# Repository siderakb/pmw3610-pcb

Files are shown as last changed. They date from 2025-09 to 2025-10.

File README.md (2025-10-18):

# PMW3610 PCB




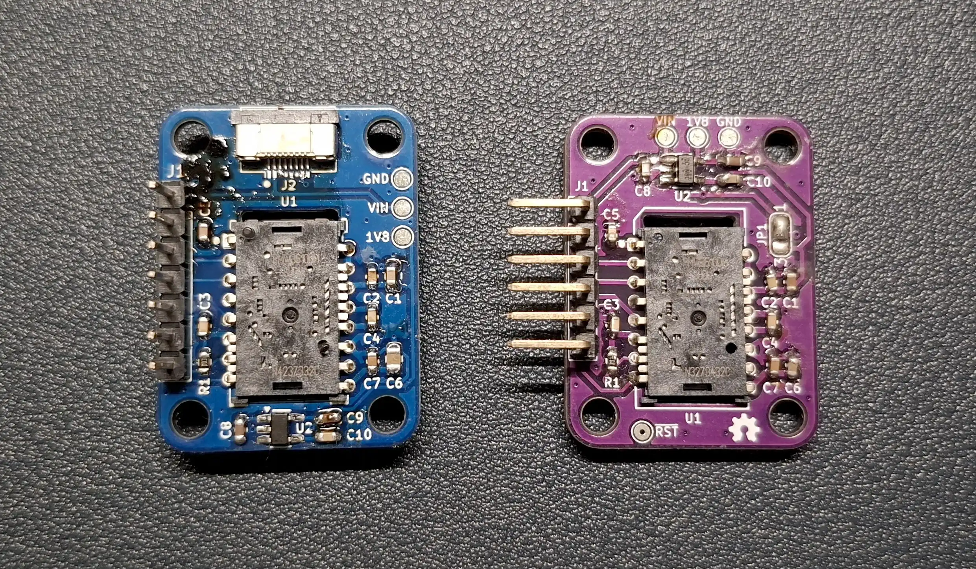
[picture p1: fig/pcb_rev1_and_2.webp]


Breakout board for the [PixArt PMW3610DM-SUDU](https://www.pixart.com/products-detail/21/PMW3610DM-SUDU), a low-power laser mouse sensor. An alternative to the [PMW3360 PCB](https://github.com/siderakb/pmw3360-pcb) for low-power applications. Can be used to make a mouse or trackball.

✨ Features:

- Compatible with [ZMK](https://zmk.dev/) projects. [Demo video](https://youtu.be/nyLZ6U8h7f0?t=17)
- Operates at either 1.8V or 3.3V voltage levels.
- Supports both 2.54mm pin headers and 0.5mm-pitch FFC/FPC connectors.
- The optical center of the sensor is located in the center of the PCB.

## PCB

Online preview available [here](https://kicanvas.org/?github=https%3A%2F%2Fgithub.com%2Fsiderakb%2Fpmw3610-pcb), powered by [KiCanvas](https://github.com/theacodes/kicanvas).

<a href="https://raw.githubusercontent.com/siderakb/pmw3610-pcb/refs/heads/main/fig/schematic.webp" target="_blank">
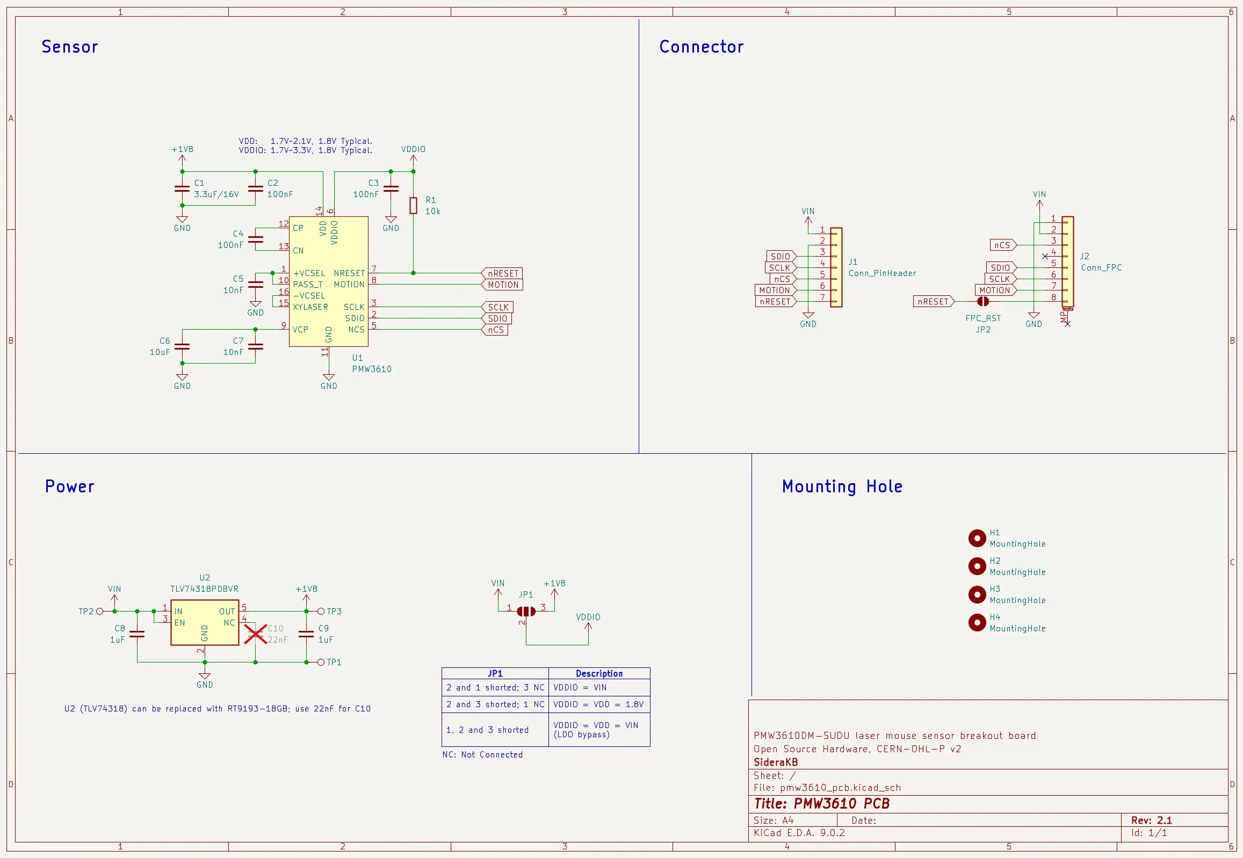
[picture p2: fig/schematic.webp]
schematic
  
</a>
<a href="https://raw.githubusercontent.com/siderakb/pmw3610-pcb/refs/heads/main/fig/layout.webp" target="_blank">
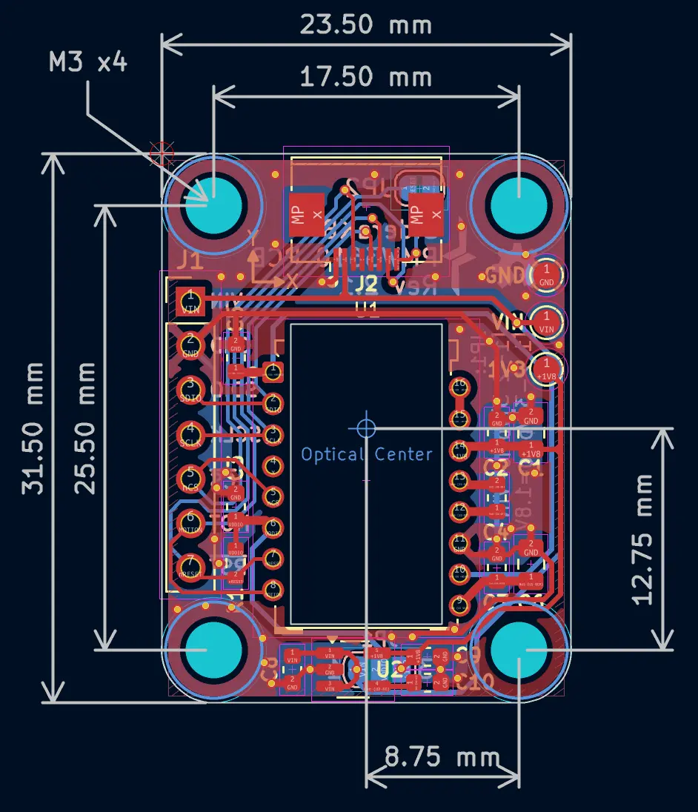
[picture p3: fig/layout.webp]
layout
  
</a>

## Docs

📖 For more detailed information, please refer to the [docs](https://siderakb.ziteh.dev/mouse-sensors/pmw3610/rev2/) ([alternative link](https://github.com/siderakb/siderakb-website/blob/starlight/main/src/content/docs/mouse-sensors/pmw3610/rev2.md)).

[Changelog](./CHANGELOG.md)

## License

- **Hardware**: Available under the [CERN-OHL-P v2](/LICENSE) permissive license.
- **Firmware**: Licensed under [Apache 2.0](https://spdx.org/licenses/Apache-2.0.html) as identified by the SPDX in each file.

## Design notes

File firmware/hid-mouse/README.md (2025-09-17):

# HID Mouse

This is a NCS (ZephyrRTOS) sample using the PMW3610 motion sensor with the nRF52840-DK. Refer to [pixart,pmw3610 (on spi bus) — Zephyr Project Documentation](https://docs.zephyrproject.org/latest/build/dts/api/bindings/input/pixart%2Cpmw3610.html).

Setup NCS: [nRF Connect SDK Fundamentals - Nordic Developer Academy](https://academy.nordicsemi.com/courses/nrf-connect-sdk-fundamentals/)

Pin mapping:

| PMW3610 PCB | nRF52840 |
| :---: | :---: |
| SDIO | `P0.31`  |
| SCLK | `P0.30`  |
| CS | `P0.29`  |
| MOTION | `P0.28`  |
| RESET | NC |

RTT logging backend. Example log:

```log
*** Booting nRF Connect SDK v3.1.0-6c6e5b32496e ***
*** Using Zephyr OS v4.1.99-1612683d4010 ***
[00:00:00.419,250] <inf> main: Starting PMW3610 example
[00:00:00.419,433] <inf> main: USB HID Initialized
[00:00:07.137,878] <inf> main: Motion X: 2
[00:00:07.137,908] <inf> main: Motion Y: -4
[00:00:07.141,143] <inf> main: Motion X: 4
[00:00:07.141,143] <inf> main: Motion Y: -10
[00:00:07.145,874] <inf> main: Motion X: 5
[00:00:07.145,874] <inf> main: Motion Y: -11
[00:00:07.149,139] <inf> main: Motion X: 7
[00:00:07.149,169] <inf> main: Motion Y: -14
[00:00:07.153,869] <inf> main: Motion X: 8
[00:00:07.153,900] <inf> main: Motion Y: -18
[00:00:07.157,897] <inf> main: Motion X: 8
[00:00:07.157,897] <inf> main: Motion Y: -17
[00:00:07.161,163] <inf> main: Motion X: 9
[00:00:07.161,193] <inf> main: Motion Y: -20
[00:00:07.165,893] <inf> main: Motion X: 8
[00:00:07.165,924] <inf> main: Motion Y: -19
[00:00:07.323,974] <inf> main: Motion X: 2
```

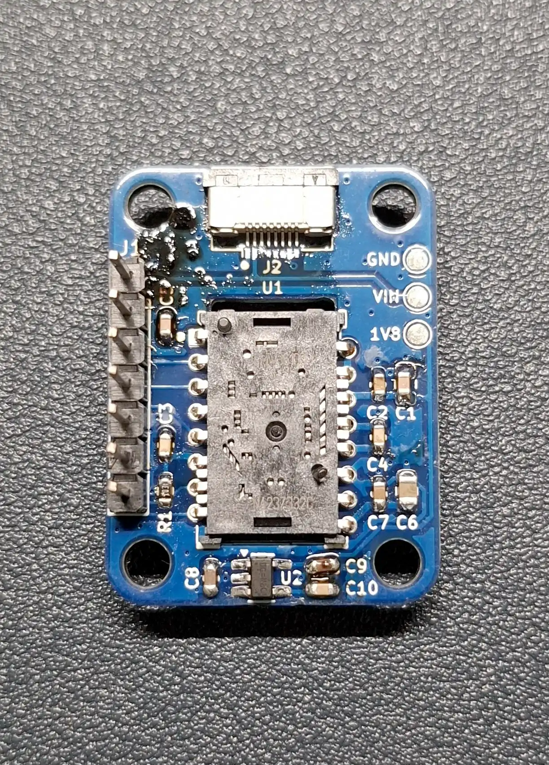
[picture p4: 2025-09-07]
fig/pcb_rev2.webp

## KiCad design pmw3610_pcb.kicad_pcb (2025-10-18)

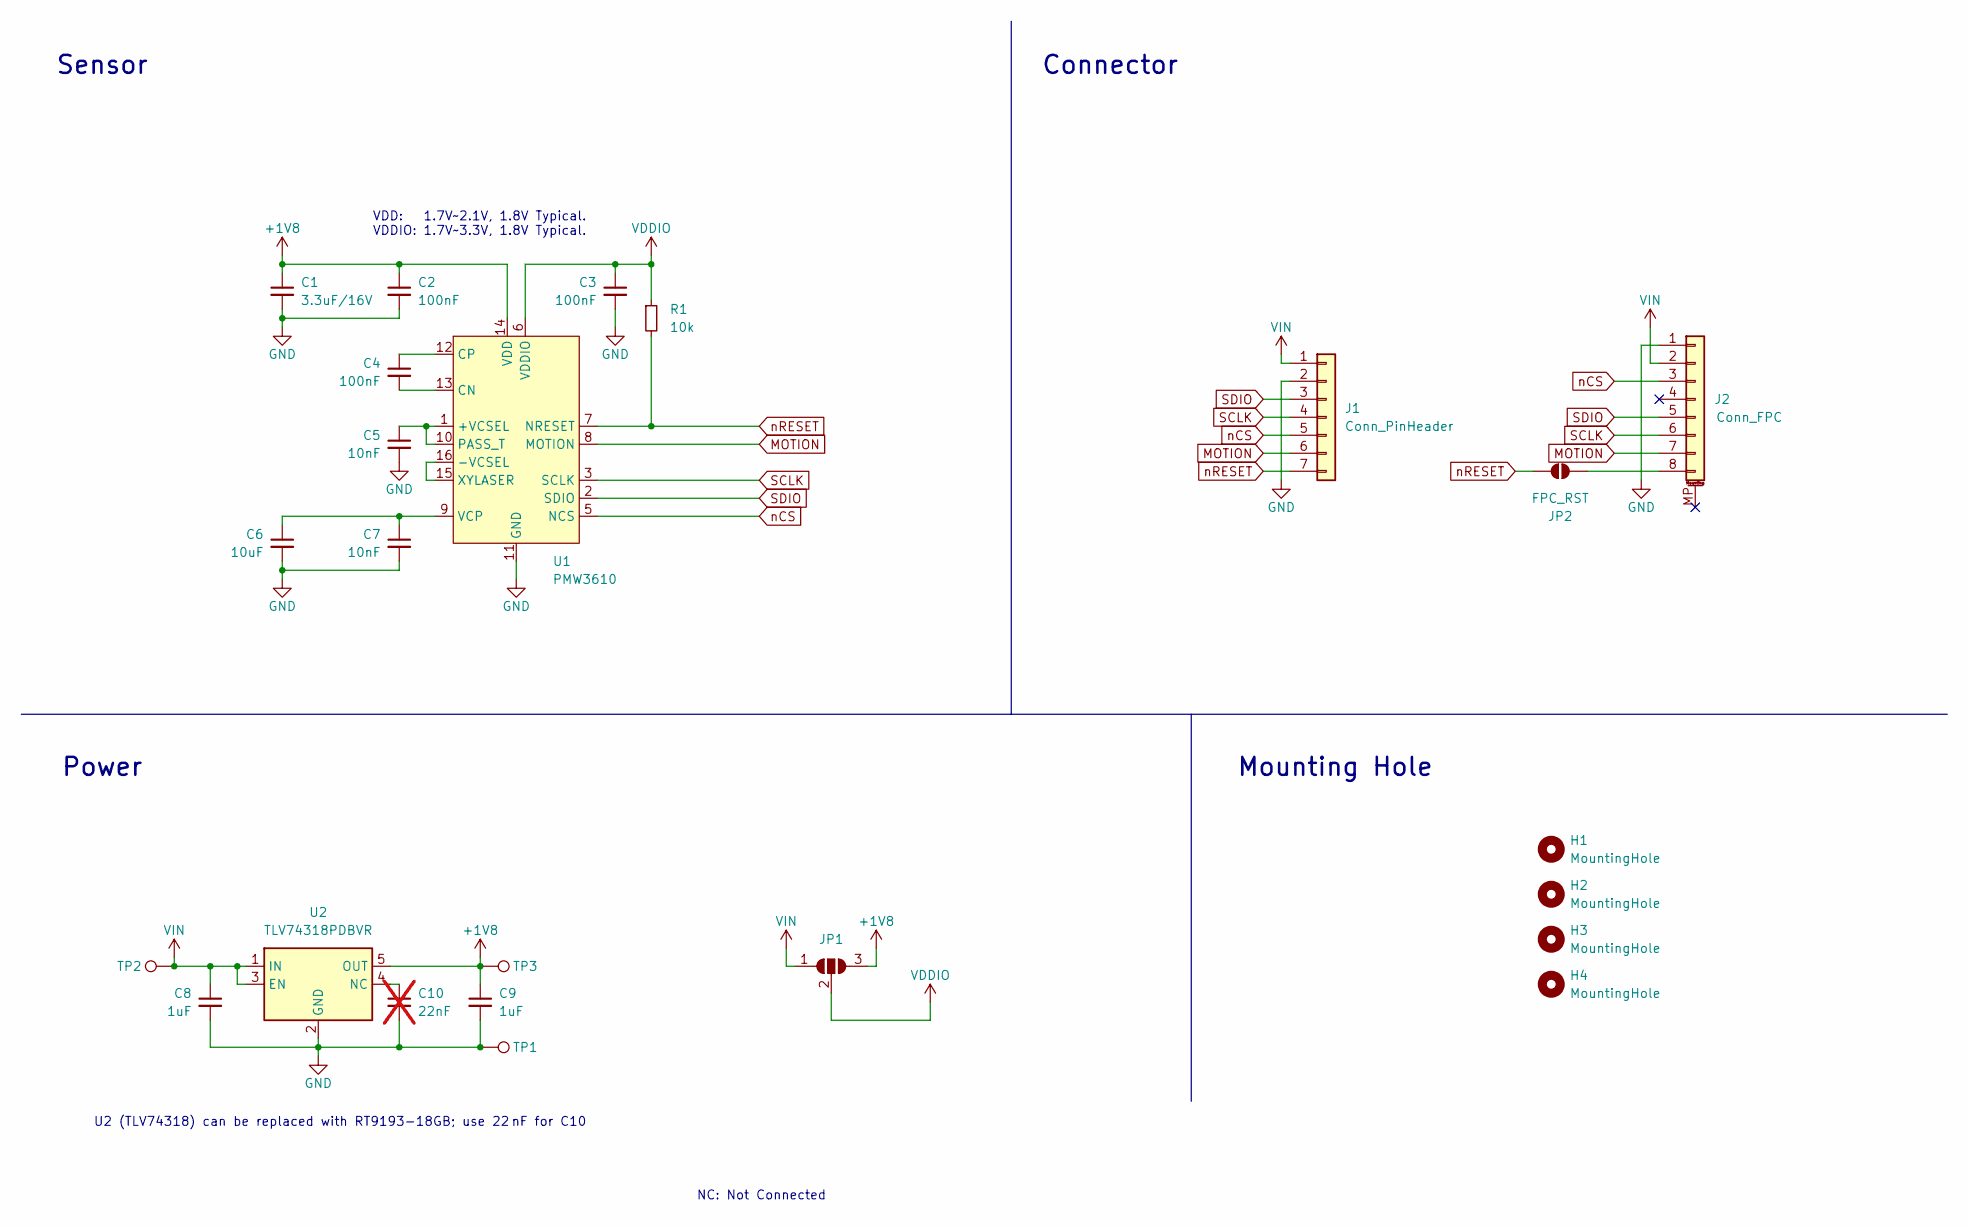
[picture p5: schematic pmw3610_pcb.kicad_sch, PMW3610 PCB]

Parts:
C1: 3.3uF/16V; C_0805_2012Metric; MFR. Part # TCC0805X7R335K250FT; JLCPCB Part # C7393948
C2, C3, C4: 100nF; C_0603_1608Metric; MFR. Part # CC0603KRX7R9BB104; JLCPCB Part # C14663
C5, C7: 10nF; C_0603_1608Metric; MFR. Part # 0603B103K500NT; JLCPCB Part # C57112
C6: 10uF; C_0805_2012Metric; MFR. Part # CL21A106KAYNNNE; JLCPCB Part # C15850
C8, C9: 1uF; C_0603_1608Metric; MFR. Part # CL10A105KB8NNNC; JLCPCB Part # C15849
C10: 22nF; C_0603_1608Metric; MFR. Part # CL10B223KB8NNNC; JLCPCB Part # C21122; not fitted
H1, H2, H3, H4: MountingHole; MountingHole_3.2mm_M3_ISO14580
J1: Conn_PinHeader; PinHeader_1x07_P2.54mm_Vertical
J2: Conn_FPC; FPC_8P_0.5mm_AFC01-S08FCA-00; MFR. Part # AFC01-S08FCA-00; JLCPCB Part # C262657
JP1: SolderJumper_3_Open; SolderJumper-3_P1.3mm_Open_RoundedPad1.0x1.5mm_NumberLabels
JP2: FPC_RST; SolderJumper-2_P1.3mm_Open_RoundedPad1.0x1.5mm
R1: 10k; R_0603_1608Metric; MFR. Part # 0603WAF1002T5E; JLCPCB Part # C25804
TP1, TP2, TP3: TestPoint; TestPoint_Pad_D1.5mm
U1: PMW3610; PMW3610DM-SUDU 16Pin; MFR. Part # PMW3610DM-SUDU; JLCPCB Part # C42442560
U2: TLV74318PDBVR; SOT-23-5_HandSoldering; MFR. Part # TLV74318PDBVR; JLCPCB Part # C485152

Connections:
+1V8: C1.1, C2.1, C9.1, JP1.3 (B), TP3.1, U1.14 (VDD), U2.5 (OUT)
GND: C1.2, C2.2, C3.2, C5.2, C6.2, C7.2, C8.2, C9.2, C10.2, J1.2, J2.1, TP1.1, U1.11 (GND), U2.2 (GND)
MOTION: J1.6, J2.7, U1.8 (MOTION)
unnamed: J2.8, JP2.2 (B)
unnamed: C5.1, U1.1 (+VCSEL), U1.10 (PASS_T)
unnamed: U1.15 (XYLASER), U1.16 (-VCSEL)
unnamed: C4.2, U1.13 (CN)
unnamed: C4.1, U1.12 (CP)
unnamed: C6.1, C7.1, U1.9 (VCP)
unnamed: C10.1, U2.4 (NC)
SCLK: J1.4, J2.6, U1.3 (SCLK)
SDIO: J1.3, J2.5, U1.2 (SDIO)
VDDIO: C3.1, JP1.2 (C), R1.1, U1.6 (VDDIO)
VIN: C8.1, J1.1, J2.2, JP1.1 (A), TP2.1, U2.1 (IN), U2.3 (EN)
nCS: J1.5, J2.3, U1.5 (NCS)
nRESET: J1.7, JP2.1 (A), R1.2, U1.7 (NRESET)

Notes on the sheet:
U2 (TLV74318) can be replaced with RT9193-18GB; use 22 nF for C10
Sensor
Power
Mounting Hole
NC: Not Connected
Connector
VDD: 1.7V~2.1V, 1.8V Typical. VDDIO: 1.7V~3.3V, 1.8V Typical.

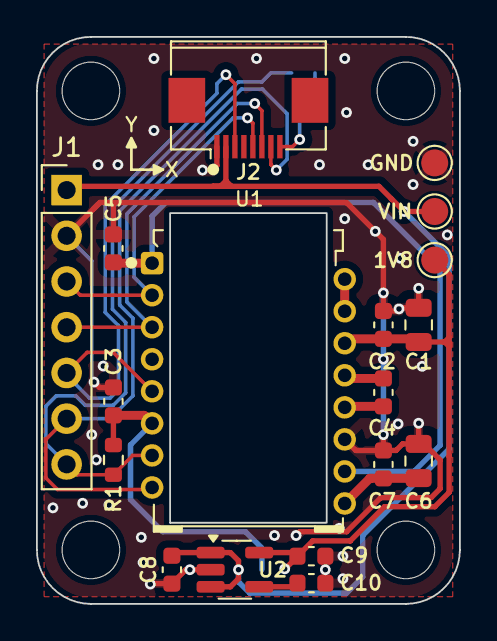
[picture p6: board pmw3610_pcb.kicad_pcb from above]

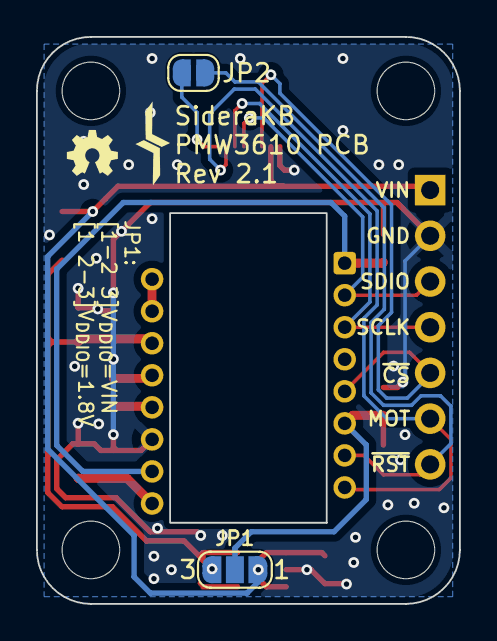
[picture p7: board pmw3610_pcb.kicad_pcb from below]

Board: 2 copper layers, 23.5 x 31.5 mm, 24 parts (6 on the bottom side), 16 nets.

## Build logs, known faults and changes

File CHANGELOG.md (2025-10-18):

# Changelog

All notable changes to this project will be documented in this file. The format is based on [Keep a Changelog](https://keepachangelog.com/en/1.1.0/).

Types of changes:

- `Added` for new features.
- `Changed` for changes in existing functionality.
- `Deprecated` for soon-to-be removed features.
- `Removed` for now removed features.
- `Fixed` for any bug fixes.
- `Security` in case of vulnerabilities.

<!-- ## Unreleased -->

## 2.1.0 - 2025-10-18

### Added

- Added jumper `JP2` to connect `J2` FFC/FPC connector and nRESET pin.

## 2.0.0 - 2025-09-07

KiCad `v9.0.2`

### Changed

- `J1` pin header connector changed from 1x07 to 1x08, adding the nRESET pin.
- Pin 8 of `J2` FFC/FPC connector changed from NC to nRESET.
- Changed the `J2` FFC/FPC connector to the top layer,
- Changed the footprint of `C1` and `C6` from 0603 to 0805 to make it easier to find large-capacity capacitors with recommended specifications.
- `R1` nRESET pull-up resistor is no longer DNI
- Updated PMW3610 footprint.
- Increased the copper-to-board edge clearance to 0.4mm for better V-cut panelization.

### Added

- Added the manufacturer and JLCPCB part number to each component for PCBA.

### Removed

- Removed the test point for nRESET.

## 1.0.0 - 2024-01-28

KiCad `v7`

First release.

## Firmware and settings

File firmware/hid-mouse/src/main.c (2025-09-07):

/*
 * Copyright (c) 2025 ZiTe SideraKB
 * Copyright (c) 2018 qianfan Zhao
 * Copyright (c) 2018, 2023 Nordic Semiconductor ASA
 *
 * SPDX-License-Identifier: Apache-2.0
 */

#include <sample_usbd.h>

#include <string.h>

#include <zephyr/kernel.h>
#include <zephyr/device.h>
#include <zephyr/drivers/gpio.h>
#include <zephyr/input/input.h>
#include <zephyr/sys/util.h>

#include <zephyr/usb/usb_device.h>
#include <zephyr/usb/usbd.h>
#include <zephyr/usb/class/usb_hid.h>

#include <zephyr/logging/log.h>
LOG_MODULE_REGISTER(main, LOG_LEVEL_INF);

static const struct device *motion_sensor = DEVICE_DT_GET(DT_NODELABEL(pmw3610));
static const struct gpio_dt_spec led0 = GPIO_DT_SPEC_GET(DT_ALIAS(led0), gpios);
static const struct gpio_dt_spec led1 = GPIO_DT_SPEC_GET(DT_ALIAS(led1), gpios);

static const uint8_t hid_report_desc[] = HID_MOUSE_REPORT_DESC(2);
static enum usb_dc_status_code usb_status;

#define MOUSE_BTN_LEFT  0
#define MOUSE_BTN_RIGHT 1

enum mouse_report_idx {
    MOUSE_BTN_REPORT_IDX = 0,
    MOUSE_X_REPORT_IDX = 1,
    MOUSE_Y_REPORT_IDX = 2,
    MOUSE_WHEEL_REPORT_IDX = 3,
    MOUSE_REPORT_COUNT = 4,
};

K_MSGQ_DEFINE(mouse_msgq, MOUSE_REPORT_COUNT, 2, 1);
static K_SEM_DEFINE(ep_write_sem, 0, 1);

#if defined(CONFIG_USB_DEVICE_STACK_NEXT)
static int enable_usb_device_next(void) {
    struct usbd_context *sample_usbd;
    int err;

    sample_usbd = sample_usbd_init_device(NULL);
    if (sample_usbd == NULL) {
        LOG_ERR("Failed to initialize USB device");
        return -ENODEV;
    }

    err = usbd_enable(sample_usbd);
    if (err) {
        LOG_ERR("Failed to enable device support");
        return err;
    }

    LOG_DBG("USB device support enabled");

    return 0;
}
#endif /* defined(CONFIG_USB_DEVICE_STACK_NEXT) */

static inline void hid_status_cb(enum usb_dc_status_code status, const uint8_t *param) {
    usb_status = status;
}

static void hid_int_in_ready_cb(const struct device *dev) {
    ARG_UNUSED(dev);
    k_sem_give(&ep_write_sem);
}

static const struct hid_ops ops = {
    .int_in_ready = hid_int_in_ready_cb,
};

static void hid_thread_entry(void) {
    const struct device *hid_dev;
    int ret;

#if defined(CONFIG_USB_DEVICE_STACK_NEXT)
    hid_dev = DEVICE_DT_GET_ONE(zephyr_hid_device);
#else
    hid_dev = device_get_binding("HID_0");
#endif
    if (hid_dev == NULL) {
        LOG_ERR("Cannot get USB HID Device");
        return;
    }

    usb_hid_register_device(hid_dev, hid_report_desc, sizeof(hid_report_desc), &ops);
    ret = usb_hid_init(hid_dev);
    if (ret) {
        LOG_ERR("Failed to initialize USB HID");
        return;
    }

#if defined(CONFIG_USB_DEVICE_STACK_NEXT)
    ret = enable_usb_device_next();
#else
    ret = usb_enable(hid_status_cb);
#endif
    if (ret) {
        LOG_ERR("Failed to enable USB");
        return;
    }

    LOG_INF("USB HID Initialized");

    while (true) {
        UDC_STATIC_BUF_DEFINE(report, MOUSE_REPORT_COUNT);

        k_msgq_get(&mouse_msgq, &report, K_FOREVER);

        ret = hid_int_ep_write(hid_dev, report, MOUSE_REPORT_COUNT, NULL);
        if (ret) {
            LOG_ERR("HID write error, %d", ret);
        } else {
            k_sem_take(&ep_write_sem, K_FOREVER);
            (void)gpio_pin_toggle(led1.port, led1.pin);
        }
    }
}

K_THREAD_STACK_DEFINE(hid_thread_stack, 1024);
K_THREAD_DEFINE(hid_thread, K_THREAD_STACK_SIZEOF(hid_thread_stack), hid_thread_entry, NULL, NULL, NULL, K_PRIO_PREEMPT(0), 0, 0);

static ALWAYS_INLINE void rwup_if_suspended(void) {
    if (IS_ENABLED(CONFIG_USB_DEVICE_REMOTE_WAKEUP)) {
        if (usb_status == USB_DC_SUSPEND) {
            usb_wakeup_request();
            return;
        }
    }
}

static void input_cb(struct input_event *evt, void *user_data) {
    ARG_UNUSED(user_data);

    static int8_t tmp[MOUSE_REPORT_COUNT];
    bool should_send_report = false;

    switch (evt->code) {
    case INPUT_KEY_0:
        rwup_if_suspended();
        WRITE_BIT(tmp[MOUSE_BTN_REPORT_IDX], MOUSE_BTN_LEFT, evt->value);
        should_send_report = true;
        break;

    case INPUT_KEY_1:
        rwup_if_suspended();
        WRITE_BIT(tmp[MOUSE_BTN_REPORT_IDX], MOUSE_BTN_RIGHT, evt->value);
        should_send_report = true;
        break;

    case INPUT_REL_X: {
        int v = CLAMP(evt->value, -127, 127);
        tmp[MOUSE_X_REPORT_IDX] = (int8_t)(tmp[MOUSE_X_REPORT_IDX] + v);
        LOG_INF("Motion X: %d", v);
        should_send_report = false; /* Wait for possible Y axis data */
        break;
    }

    case INPUT_REL_Y: {
        int v = CLAMP(evt->value, -127, 127);
        tmp[MOUSE_Y_REPORT_IDX] = (int8_t)(tmp[MOUSE_Y_REPORT_IDX] + v);
        LOG_INF("Motion Y: %d", v);
        should_send_report = true;
        break;
    }

    default:
        LOG_INF("Unrecognized input code %u value %d", evt->code, evt->value);
        return;
    }

    if (should_send_report && (usb_status == USB_DC_CONFIGURED)) {
        if (k_msgq_put(&mouse_msgq, tmp, K_NO_WAIT) != 0) {
            LOG_ERR("Failed to put new input event");
        }

        tmp[MOUSE_X_REPORT_IDX] = 0;
        tmp[MOUSE_Y_REPORT_IDX] = 0;
    }
}

INPUT_CALLBACK_DEFINE(NULL, input_cb, NULL);

static int led_init(void) {
    int ret;

    if (!gpio_is_ready_dt(&led0)) {
        LOG_ERR("LED device %s is not ready", led0.port->name);
        return -1;
    }

    ret = gpio_pin_configure_dt(&led0, GPIO_OUTPUT);
    if (ret) {
        LOG_ERR("Failed to configure the LED pin, error: %d", ret);
        return -1;
    }

    if (!gpio_is_ready_dt(&led1)) {
        LOG_ERR("LED device %s is not ready", led1.port->name);
        return -1;
    }

    ret = gpio_pin_configure_dt(&led1, GPIO_OUTPUT);
    if (ret) {
        LOG_ERR("Failed to configure the LED pin, error: %d", ret);
        return -1;
    }

    return 0; /* Ok */
}

static int motion_sensor_init(void) {
    if (!device_is_ready(motion_sensor)) {
        LOG_ERR("Motion sensor device not ready");
        return -1;
    }

    return 0; /* Ok */
}

int main(void) {
    int ret;

    LOG_INF("Starting PMW3610 example");

    ret = led_init();
    if (ret) {
        LOG_ERR("Failed to initialize LEDs");
        return 0;
    }

    ret = motion_sensor_init();
    if (ret) {
        LOG_ERR("Failed to initialize motion sensor");
        return 0;
    }

    while (true) {
        (void)gpio_pin_toggle(led0.port, led0.pin);
        k_msleep(1000);
    }
    return 0;
}

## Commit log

2023-10-07 Init commit
    [pmw3610_pcb.kicad_pcb, pmw3610_pcb.kicad_sch]
2023-10-07 Add KiCad project files
    [pmw3610_pcb.kicad_pcb, pmw3610_pcb.kicad_sch]
2023-10-20 Add `J2` FPC/FFC connecter
    [pmw3610_pcb.kicad_pcb, pmw3610_pcb.kicad_sch]
2023-11-14 Create LICENSE
    [pmw3610_pcb.kicad_pcb, pmw3610_pcb.kicad_sch]
2025-07-17 feat: update PCB rev 1.1
    [pmw3610_pcb.kicad_pcb, pmw3610_pcb.kicad_sch]
2025-07-18 feat: update PMW3610 footprint
    [pmw3610_pcb.kicad_pcb]
2025-07-18 feat: increase the copper to board edge clearance to 0.4mm for better V-cut panelization
    [pmw3610_pcb.kicad_pcb]
2025-07-20 feat: update FPC connector symbol
    [pmw3610_pcb.kicad_pcb, pmw3610_pcb.kicad_sch]
2025-07-22 feat: changed the J2 to the top layer
    [pmw3610_pcb.kicad_pcb, pmw3610_pcb.kicad_sch]
2025-07-22 feat: update part number of J2
    [pmw3610_pcb.kicad_pcb, pmw3610_pcb.kicad_sch]
2025-09-07 feat: add axis mark
    [pmw3610_pcb.kicad_pcb]
2025-09-07 docs: update pixart pmw3610 device link
2025-10-18 feat: add jumper JP2 for FFC/FPC and nRESET pin
    [pmw3610_pcb.kicad_pcb, pmw3610_pcb.kicad_sch]

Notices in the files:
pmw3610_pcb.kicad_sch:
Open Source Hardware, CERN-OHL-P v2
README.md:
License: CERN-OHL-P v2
